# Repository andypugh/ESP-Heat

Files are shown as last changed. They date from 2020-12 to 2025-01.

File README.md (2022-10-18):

ESP32 Heating Controller
==============

A multi-zone central heating controller based on the ESP32.

It can be configured for an almost unlimited number of zones, pumps and separate boilers.
Boiler run-on is supported, and configurable. 
Temperature sensing assumes DS18B20 sensors. 
One zone per valve, and it is assumed that zone valves trip microswitches when open. 
 
Branches: 
no_master: Uses GPIO to read from the DS18B20 sensors

master: using a DS2482 1-wire master adaptor for longer cable runs. Using WebServer
to handle http requests. 

WiFiServer: Initial version using wiFi server and parsing incoming URLs byte-by-byte
 
The DS2482-100 is a I2C->1-Wire bridge (http://www.maximintegrated.com/datasheet/index.mvp/id/4382),
contains functionality that means it is better at driving long and complex networks. 

I used a DS2482-800 which additionally expands the bus to 8 separate channels, which allows
for longer single-ended networks.
For simplicity, using this break-out board. 
https://uk.rs-online.com/web/p/communication-wireless-development-tools/1360731/

Here is the main screen, showing a diagram of the house, with the temperature of each zone. 
The shape and position of each room is defined by an SVG path, for example:
"M250 350 v190 h140 v-190 z"
So that almost any house layout (or limited graphical elements for tanks etc) can be defined. 

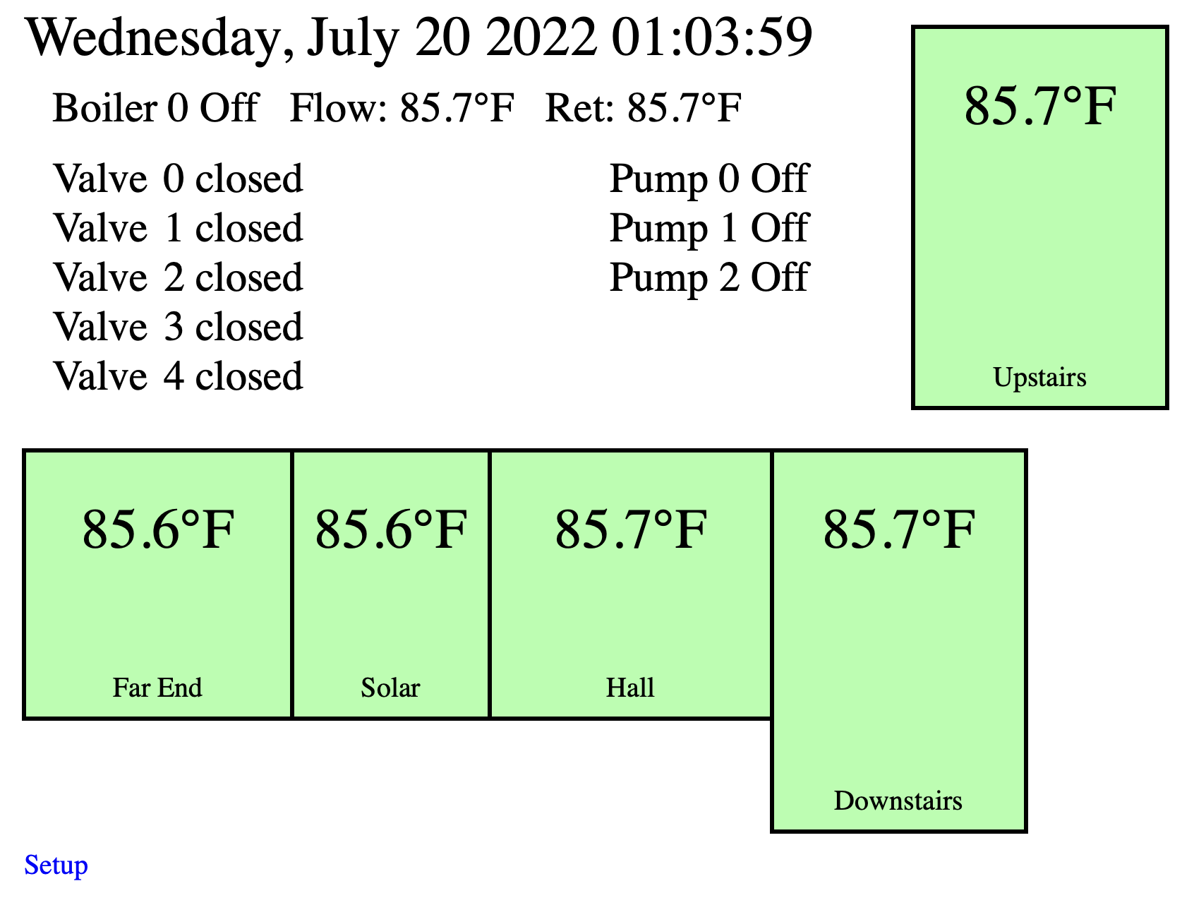
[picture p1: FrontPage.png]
Status screen
<kbd></kbd>

Here is one of the programming screens

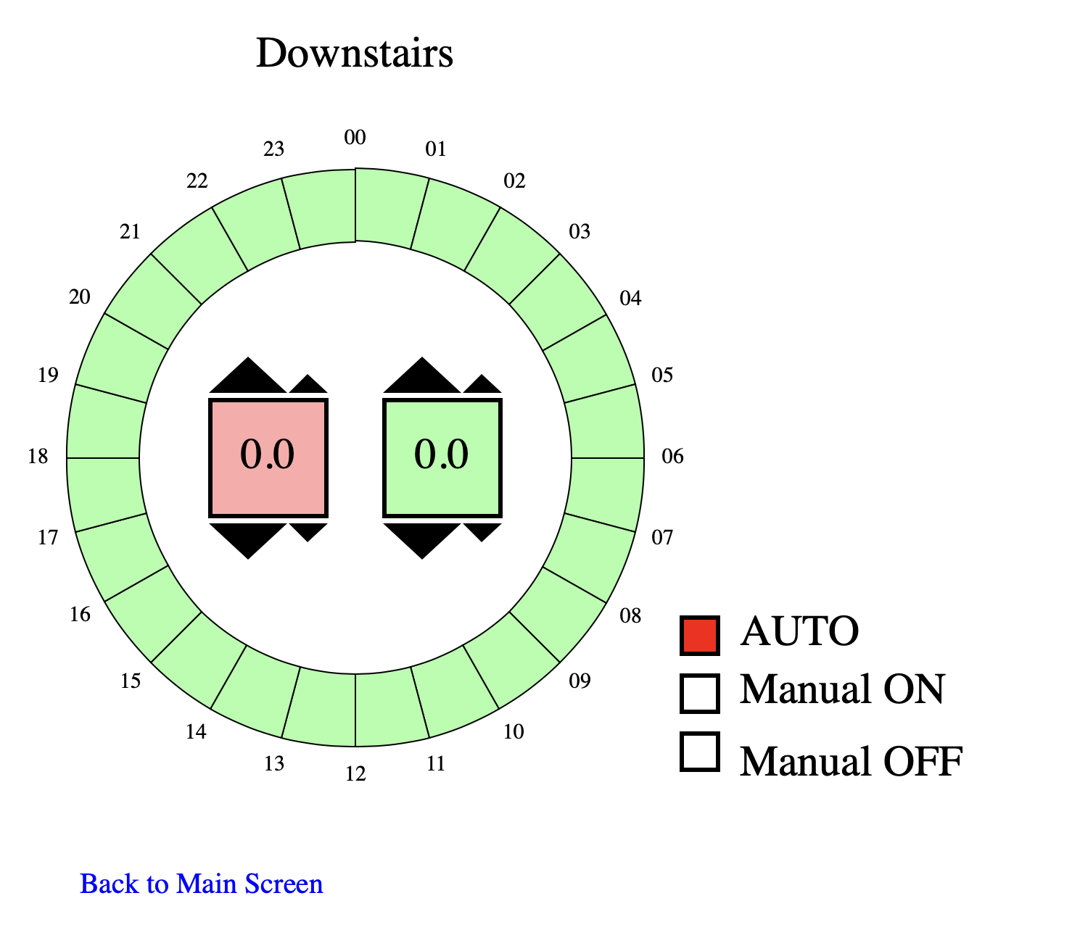
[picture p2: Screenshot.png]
Programming screen for one zone
<kbd></kbd>

And the setup screen where the pins for each valve and pump etc can be defined, as well
as the house layout and the temperature sensor allocation. 

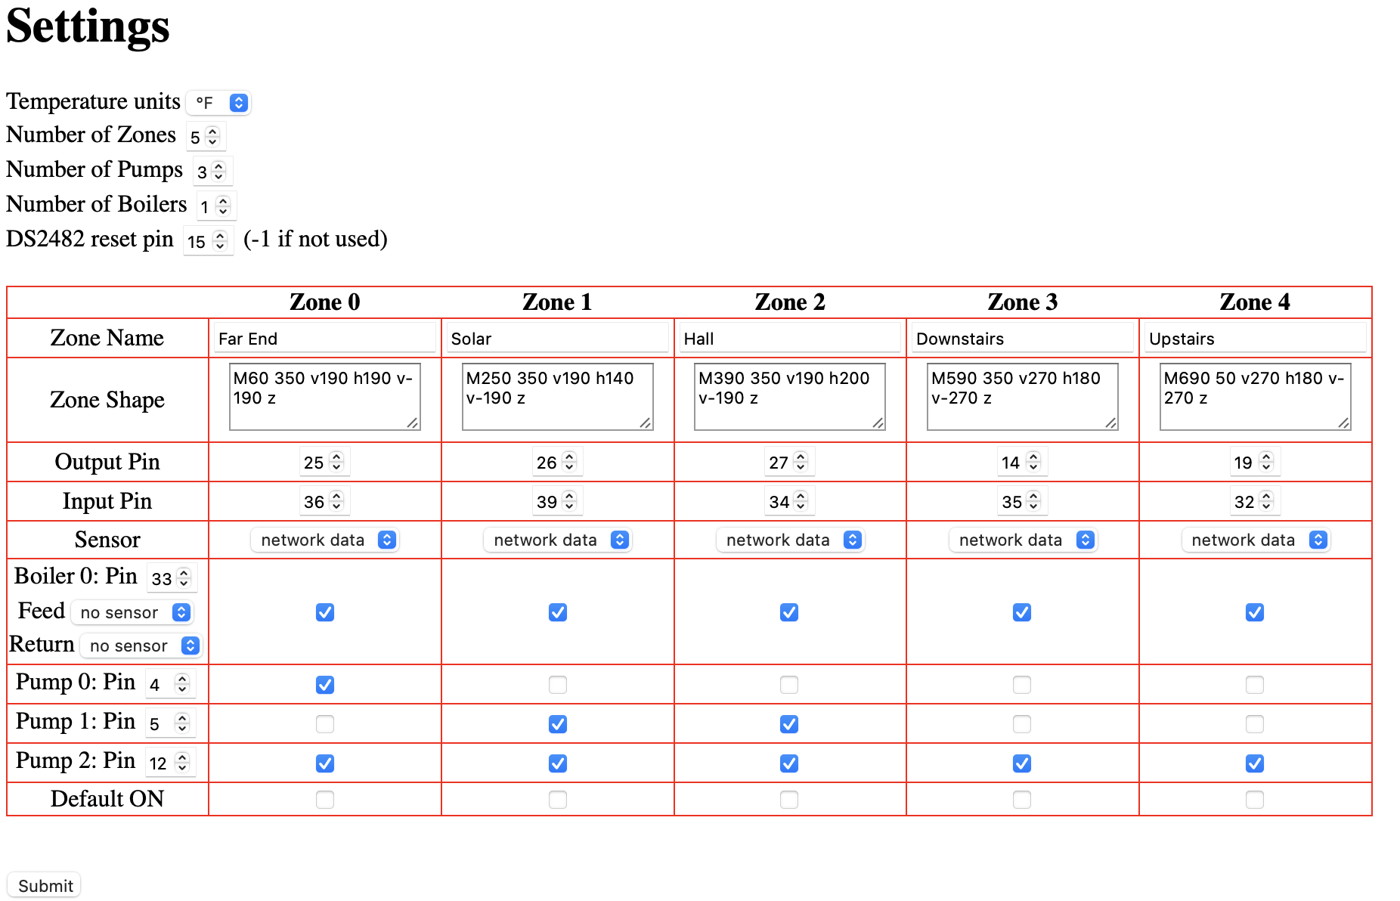
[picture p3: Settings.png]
Setup / Configuration Screen
<kbd></kbd>

And here is one iteration of the hardware installed in a consumer unit case with
Neutrik connectors for the pumps and valves and CB connectors for the temperature sensors:

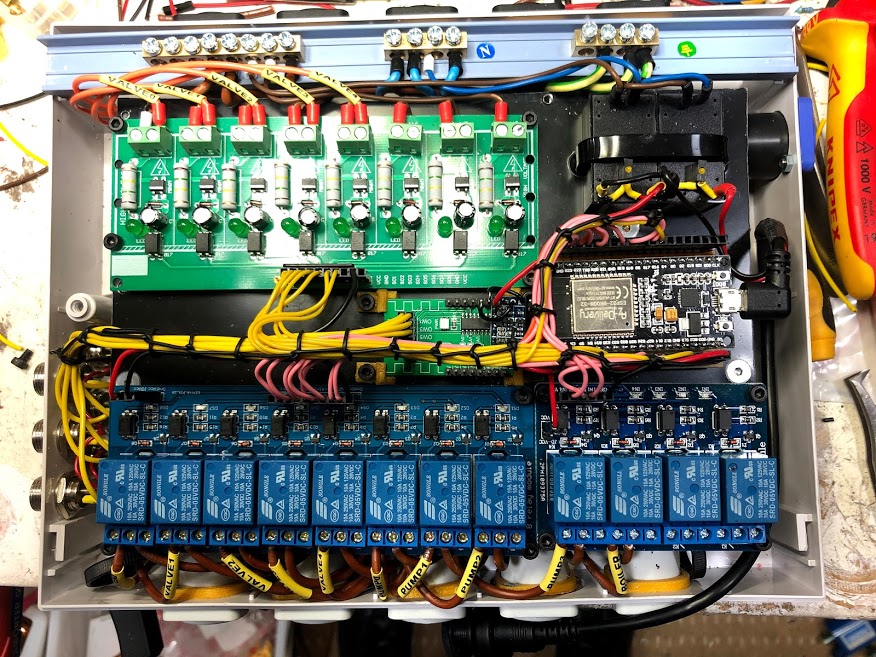
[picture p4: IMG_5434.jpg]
Hardware
<kbd></kbd>

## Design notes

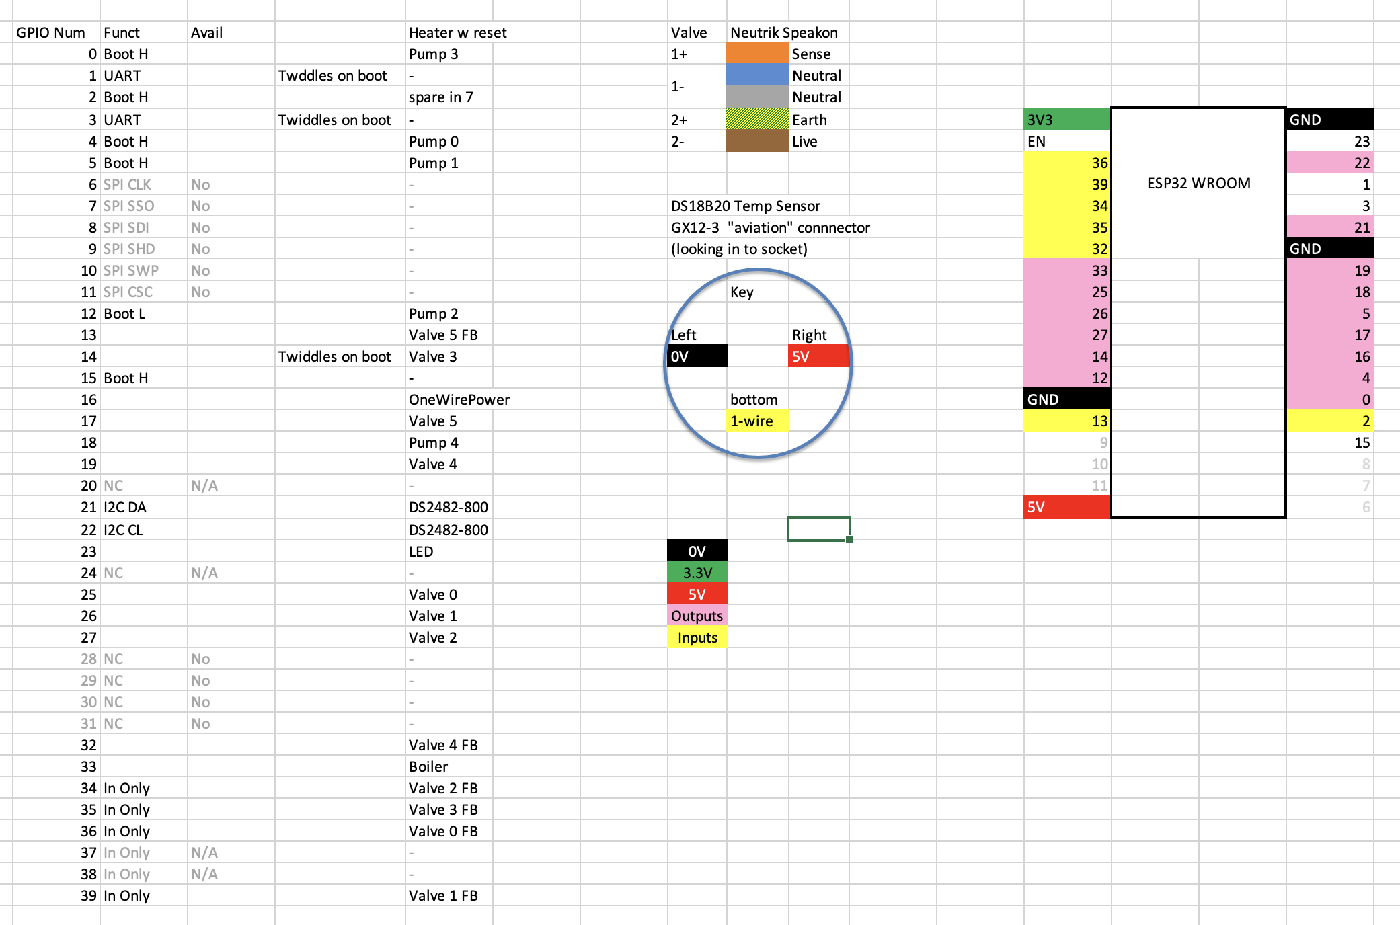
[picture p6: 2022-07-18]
Pinouts.png

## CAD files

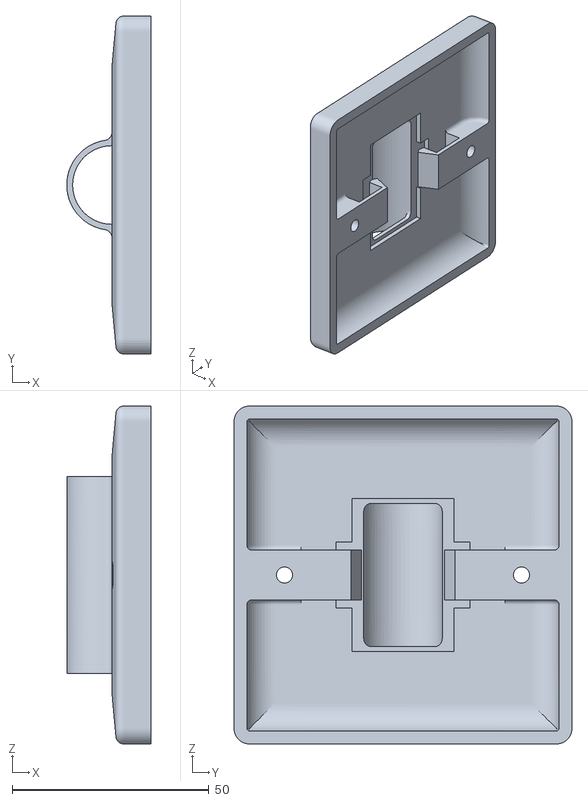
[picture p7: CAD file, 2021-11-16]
hardware/3D_Models/Temp Sensor v6.stl
21.5 x 86.0 x 86.0

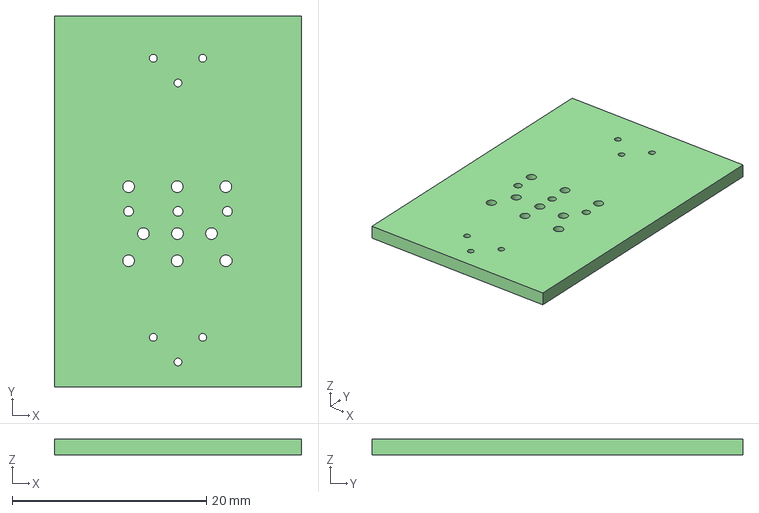
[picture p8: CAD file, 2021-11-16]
hardware/KiCad/Temp~Sensor.step
25.4 x 38.1 x 1.60 mm

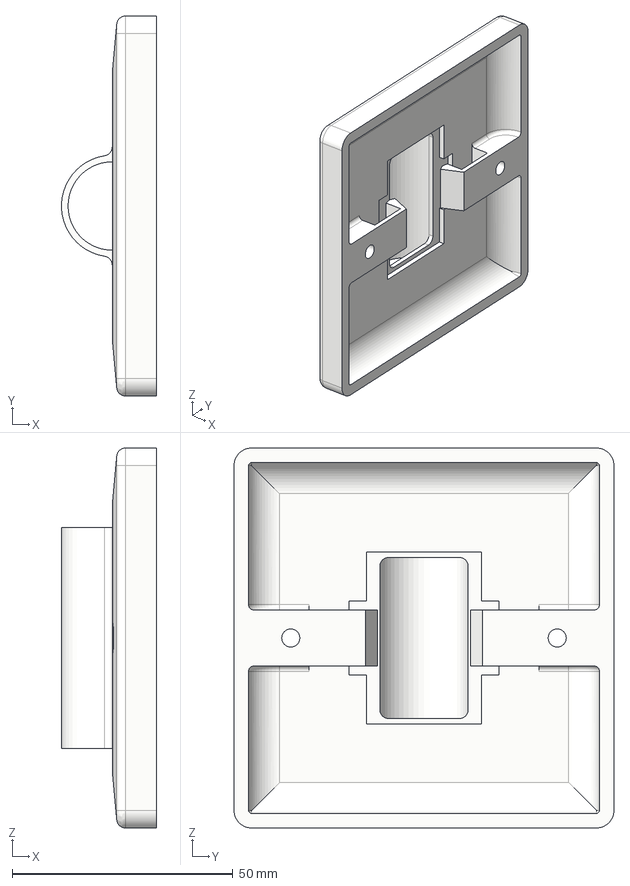
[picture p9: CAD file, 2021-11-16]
hardware/3D_Models/Temp Sensor v7.step
21.5 x 86.0 x 86.0 mm

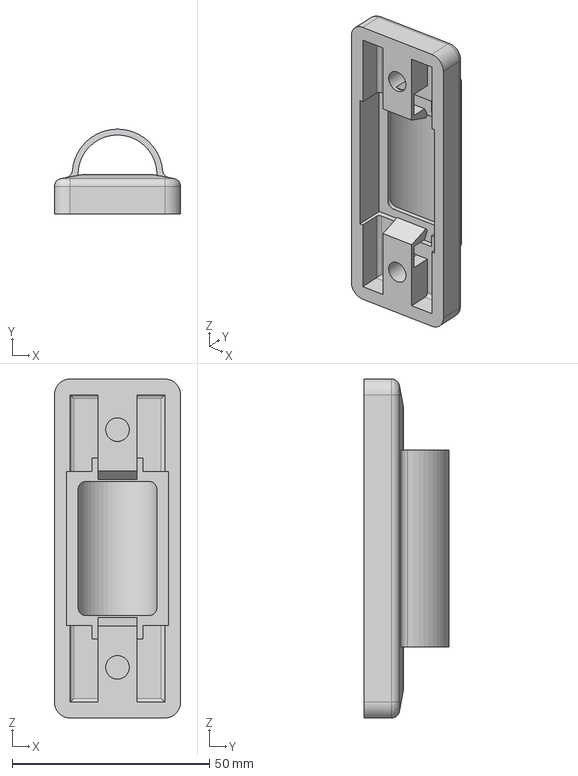
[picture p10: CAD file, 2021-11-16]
hardware/3D_Models/Temp Sensor - Architrave_Ds18B20 Holder - nut v2.step
32.0 x 21.5 x 86.0 mm

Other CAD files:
hardware/3D_Models/Temp Sensor - Architrave_Ds18B20 Holder - nut v2.f3d
hardware/3D_Models/Temp Sensor - Architrave_Ds18B20 Holder - nut v2.stl
hardware/3D_Models/Temp Sensor v6.f3z

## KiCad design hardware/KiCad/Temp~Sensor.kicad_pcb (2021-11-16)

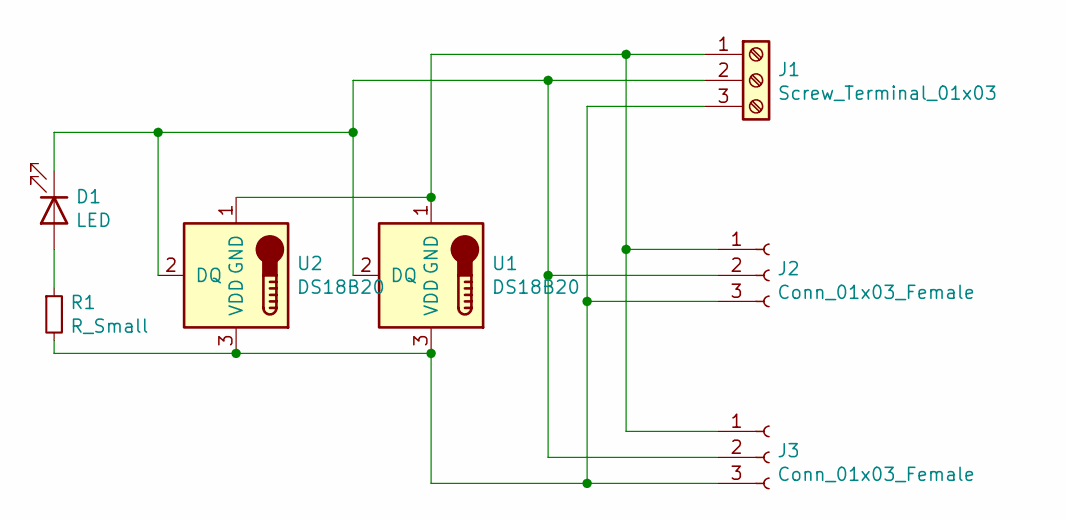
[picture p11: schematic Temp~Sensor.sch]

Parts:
D1: LED; LED_0603_HandSoldering
J1: Screw_Terminal_01x03; PhoenixContact_MCV-G_03x3.50mm_Vertical
J2: Conn_01x03_Female; Amphenol_FCI_3
J3: Conn_01x03_Female; RSProClamp
R1: R_Small; R_0603_HandSoldering
U1, U2: DS18B20; TO-92_Molded_Wide_Reverse

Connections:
unnamed: D1.1 (K), J1.2, J2.2, J3.2, U1.2 (DQ), U2.2 (DQ)
unnamed: D1.2 (A), R1.1
unnamed: J1.1, J2.1, J3.1, U1.1 (GND), U2.1 (GND)
unnamed: J1.3, J2.3, J3.3, R1.2, U1.3 (VDD), U2.3 (VDD)

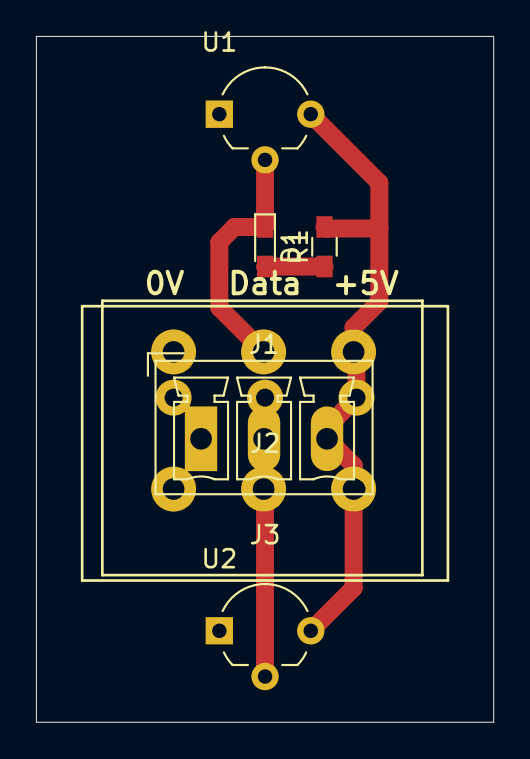
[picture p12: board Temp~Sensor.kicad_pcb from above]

Board: 2 copper layers, 25.4 x 38.1 mm, 7 parts (0 on the bottom side), 4 nets.

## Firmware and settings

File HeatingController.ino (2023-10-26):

 /*********
  Andy Pugh 2020

  Based on work by Rui Saontos: https://randomnerdtutorials.com
*********/

// Load Wi-Fi library

#include <WiFi.h>
#include <AsyncTCP.h>
#include <ESPAsyncWebServer.h>
#include <AsyncElegantOTA.h>
#include "ESP_Mail_Client.h"
#include "time.h"
#include "EEPROM.h"
// https://github.com/cybergibbons/DS2482_OneWire _NOT_ the standard library
// If using the DS2482. Otherwise use the standard OneWire lib
#include <OneWire.h>
#include <DallasTemperature.h>
#include "config.h"
#include "globals.h"

#define __P(f_, ...) snprintf (buffer, 200, (f_), ##__VA_ARGS__) ; content += buffer ;
//#define __P(f_, ...) snprintf (buffer, 200, (f_), ##__VA_ARGS__) ; Serial.println(buffer);

#ifdef USE_DS2482
OneWire oneWire(0); //I2C device address 0
#else
OneWire oneWire(23); //Bitbanged device, pin 23
#endif

DallasTemperature sensors(&oneWire);

// Set web server port number to 80
AsyncWebServer server(80);

int error_flag = 2; // 1 flash is just a heartbeat. use 2 to send reboot email

void setup() {
  int connection_count;

  Serial.begin(115200);
  
  EEPROM.begin(EEPROM_SIZE);

  pinMode(0, INPUT_PULLUP);

  // Get setup from eeprom
  read_EEPROM(EEPROM_BASE, true);
  read_EEPROM(CREDENTIALS_BASE, false);
  // Connect to Wi-Fi network with SSID and password
  Serial.print(" Connecting to ");
  Serial.println(ssid);
  WiFi.disconnect();
  WiFi.mode(WIFI_OFF);
  delay(1000);
  WiFi.config(INADDR_NONE, INADDR_NONE, INADDR_NONE, INADDR_NONE);
  WiFi.setHostname(hostname);
  WiFi.begin(ssid, password);
  WiFi.mode(WIFI_STA);
  pinMode(BLINK_LED, OUTPUT);
  pins[BLINK_LED] = 'x';
  do {
    if (! digitalRead(0)){ // boot button pressed
      Serial.println("boot button");
      AP_mode();
    }
    digitalWrite(BLINK_LED, HIGH);
    delay(250);
    WiFi.begin(ssid, password);
    Serial.print(WiFi.status());
    digitalWrite(BLINK_LED, LOW);
    delay(250);
    connection_count++;
  } while (WiFi.waitForConnectResult() != WL_CONNECTED && connection_count < 60);

  // Print local IP address
  Serial.println("");
  Serial.println("WiFi connected.");
  Serial.print("IP address: ");
  Serial.println(WiFi.localIP());
  Serial.print("MAC: ");
  Serial.println(WiFi.macAddress());
  Serial.printf("esp_idf_version %s\n", esp_get_idf_version());
 
  configTime(0, 3600, ntpServer);
  setenv ("TZ", TZstr, 1);
  tzset ();   // save the TZ variable

  // Get programming from eeprom)
  for (int i = 0; i < num_zones; i++) {
    zones[i].hours= EEPROM.read(i * 8 + 0) * 0x1000000L + EEPROM.read(i * 8 + 1) * 0x10000L + EEPROM.read(i * 8 + 2) * 0x100L + EEPROM.read(i * 8 + 3) * 0x1L;
    zones[i].on_temp =  EEPROM.read(i * 8 + 4); // 0 to 128 resolution 0.5 to allow for Farenheit
    if (zones[i].on_temp > 250) zones[i].on_temp = (units) ? 140 : 40; // in case if unintialised eeprom
    zones[i].off_temp = EEPROM.read(i * 8 + 5); // 0 to 128 resolution 0.5 to allow for Farenheit
    if (zones[i].off_temp > 250) zones[i].off_temp = (units) ? 80 : 10;
  }

  for (int i = 0; i < num_boilers; i++) {
    pinMode(boilers[i].out_pin, OUTPUT);
    pins[boilers[i].out_pin] = 'x';
    digitalWrite(boilers[i].out_pin, HIGH);
  }
  for (int i = 0; i < num_zones; i++) {
    pinMode(zones[i].out_pin, OUTPUT);
    pins[zones[i].out_pin] = 'x';
    digitalWrite(zones[i].out_pin, HIGH);
  }
  for (int i = 0; i < num_zones; i++) pinMode(zones[i].in_pin, INPUT_PULLUP);
  for (int i = 0; i < num_pumps; i++) {
    pinMode(pumps[i].out_pin, OUTPUT);
    pins[pumps[i].out_pin] = 'x';
    digitalWrite(pumps[i].out_pin, HIGH);
  }

  // Find which DS2482 channel each DS18B20 sensor can be found on

  num_sensors = 0;
  
#ifdef USE_DS2482

  if (ds2482_reset >= 0){
   // pinMode(ds2482_reset, OUTPUT);
   //digitalWrite(ds2482_reset, HIGH);
   // delay(1000);
   // oneWire.deviceReset();
   // delay(1000);
   // digitalWrite(ds2482_reset, LOW); // USE NC terminals, but sense is opposite for single relay
    pins[ds2482_reset] = 'x';
   // delay(2000);
  }
  sensors.begin();
  delay(1000);
  Serial.println("Searching for DS18B20 Sensors on DS2482");
  if (!oneWire.checkPresence()){
    Serial.println("DS2482 NOT found.");
  }else{
    Serial.println("DS2482 found.");
    for (byte c = 0; c < 8; c++) {
      oneWire.setChannel(c);
      if (oneWire.wireReset()){
        sensors.begin();
        Serial.printf("Checking channel %d\n", c);
        for (int j = sensors.getDS18Count() - 1; j >= 0; j--){
          sensors.getAddress(all_sensors[num_sensors].address, j);
          byte *a = all_sensors[num_sensors].address;
          sprintf(all_sensors[num_sensors].str_address,"%02X%02X%02X%02X%02X%02X%02X%02X", 
              a[0], a[1], a[2], a[3], a[4], a[5], a[6], a[7]);
          sprintf(all_sensors[num_sensors].dot_address,"%02x.%02x.%02x.%02x.%02x.%02x.%02x.%02x", 
              a[0], a[1], a[2], a[3], a[4], a[5], a[6], a[7]);
          Serial.printf("Found device addr %s\n", all_sensors[num_sensors].dot_address);
          all_sensors[num_sensors].channel = c;
          num_sensors = min(max_sensors, ++num_sensors);
        }
        for (int z = 0; z < num_zones; z++) {
          zones[z].temp=-127;
          if (sensors.isConnected(zones[z].sensor.address) && zones[z].sensor.channel >= 0) {
            Serial.printf("    Sensor for zone %i found\n", z);
            zones[z].sensor.channel = c;
          }
        }
        for (int z = 0; z < num_boilers; z++) {
          zones[z].temp=-127;
          if (sensors.isConnected(boilers[z].f_sensor.address) && boilers[z].f_sensor.channel >= 0) {
            Serial.printf("    Flow sensor for boiler %i found\n", z);
            boilers[z].f_sensor.channel = c;
          }
          if (sensors.isConnected(boilers[z].r_sensor.address) && boilers[z].r_sensor.channel >= 0) {
            Serial.printf("    Return sensor for boiler %i found\n", z);
            boilers[z].r_sensor.channel = c;
          }
        }
      }
    }
  }
  
#else
  sensors.begin;
  Serial.println("Searching for DS18B20 Sensors");
  DeviceAddress addr;
  while (! oneWire.search(addr)){
    oneWire.reset();
    delay(250);
  }
  oneWire.reset_search();
  while (oneWire.search(all_sensors[num_sensors].address)){
      byte *a = all_sensors[num_sensors].address;
      sprintf(all_sensors[num_sensors].str_address,"%02X%02X%02X%02X%02X%02X%02X%02X", 
          a[0], a[1], a[2], a[3], a[4], a[5], a[6], a[7]);
      sprintf(all_sensors[num_sensors].dot_address,"%02x.%02x.%02x.%02x.%02x.%02x.%02x.%02x", 
          a[0], a[1], a[2], a[3], a[4], a[5], a[6], a[7]);
      Serial.printf("Found device addr %s\n", all_sensors[num_sensors].dot_address);
      all_sensors[num_sensors].channel = 0;
      num_sensors = min(max_sensors, ++num_sensors);
  }
  for (int z = 0; z < num_zones; z++) {
    zones[z].temp=-127;
    if (sensors.isConnected(zones[z].sensor.address) && zones[z].sensor.channel >= 0) {
      Serial.printf("    Sensor for zone %i found\n", z);
    }
  }

#endif
  Serial.printf("Found a total of %i sensors\n", num_sensors);

// Set unused pins to their default state
  for(int i = 0; i < 39; i++){
      if (pins[i] == '0') {
          pinMode(i, OUTPUT);
          digitalWrite(i, LOW);
      } else if (pins[i] == '1') {
          pinMode(i, OUTPUT);
          digitalWrite(i, HIGH);
      } else if (pins[i] == 'i') {
          pinMode(i, INPUT);
      }   
      
  }
// Configure and start web server
// HTTP request pages are separate files
// And they seem to need to be .h as .cpp doesn't compile

#include "FrontPage.h"
#include "handleProgramming.h"
#include "handleSettings.h"
  AsyncElegantOTA.begin(&server);
  server.begin();
}

bool temp_valid(int z) {
  if (! units) {
    if (zones[z].temp > 80 || zones[z].temp < -100) return 0;
  } else {
    if (zones[z].temp > 180 || zones[z].temp < -100) return 0;
  }
  return 1;
}

void loop() {
  int t_fault = 0;
  int z = -1; // zone index
  int h = -1; // hour index
  char header[21] = {0}; int r = 0; // header buffer and index, ignore all but the first 20 chars
  AsyncElegantOTA.loop();
  do_status(); // blink-codes and connection housekeeping
  getLocalTime(&timeinfo);
  for (z = 0; z < num_zones; z++) {
    float demand_temp;
    bool off_flag = 0;

    zones[z].temp = get_temp(zones[z].sensor);

    if ((bitRead(zones[z].hours, timeinfo.tm_hour) || bitRead(zones[z].hours, 24)) && ! bitRead(zones[z].hours, 25)) {
      demand_temp = zones[z].on_temp / 2.0;
    } else {
      demand_temp = zones[z].off_temp / 2.0;
      off_flag = true; // Used to reset valve-stuck-closed
    }

    if ( ! temp_valid(z)) {
      t_fault++;
      // Handle default behaviour in faulted state
      if (zones[z].default_state) {
        if (off_flag) {
          demand_temp = -250;
        } else {
          demand_temp = +250;
        }
      } else {
        demand_temp = -250;
      }

      if (error_flag != 6){
        zones[z].timeout = time(NULL);
        error_flag = 6;
      } else {
        if (time(NULL) - zones[z].timeout > TIMEOUT){
#ifdef USE_DS2482
          if (ds2482_reset >= 0){
            Serial.printf("Resetting DS2482 HIGH on pin %i\n", ds2482_reset);
            oneWire.deviceReset();
            digitalWrite(ds2482_reset, HIGH);
            delay(10000);
            digitalWrite(ds2482_reset, LOW);
          }
#endif
          Serial.println("Resetting oneWire");
          oneWire.reset();
          zones[z].timeout = time(NULL);
        }
      }
    }
    /*************************************
          Valve control state machine
     *************************************/
    switch (zones[z].state) {
      case 0: // closed
        if (zones[z].temp < demand_temp - hyst) {
          digitalWrite(zones[z].out_pin, LOW);
          zones[z].state = 1;
          zones[z].timeout = time(NULL);
          Serial.printf("Turning On zone %d\n", z);
        }
        break;
      case 1: // valve opening
        if (! digitalRead(zones[z].in_pin)) { // valve has opened
          bitSet(zone_on, z);
          zones[z].state = 2;
          break;
        }
        if (time(NULL) - zones[z].timeout > timeoutTime) {
          error_flag = 5;
          zones[z].state = 5;
        }
        break;
      case 2: // Valve opened
        if (zones[z].temp > demand_temp + hyst) {
          digitalWrite(zones[z].out_pin, HIGH);
          zones[z].state = 3;
          zones[z].timeout = time(NULL);
          bitClear(zone_on, z);
          Serial.printf("Turning Off zone %d\n", z);
        }
        break;
      case 3: // valve closing
        if (digitalRead(zones[z].in_pin)) { // valve has closed
          zones[z].state = 0;
          break;
        }
        if (time(NULL) - zones[z].timeout > timeoutTime) { // timeout closing
          zones[z].state = 4;
          error_flag = 4;
        }
      case 4: // Stuck Open fault: We can still control temp, and it might close
        if (digitalRead(zones[z].in_pin)) { // valve has finally closed
          bitClear(zone_on, z);
          zones[z].state = 0;
          error_flag = 1;
          break;
        }
        if (zones[z].temp > demand_temp + hyst) {
          bitClear(zone_on, z);
        } else if (zones[z].temp < demand_temp - hyst) {
          bitSet(zone_on, z);
        }
        break;
      case 5: // stuck closed fault
        digitalWrite(zones[z].out_pin, HIGH); // avoid overheating motor
        bitClear(zone_on, z); // turn off the pump
        if (off_flag) {
          zones[z].state = 0;
          error_flag = 1;
        }
        break;
      default:
        error_flag = 10;
    }
  }

  if (t_fault == 0 && error_flag == 6) error_flag = 1;

  /*********************************
         Boiler State Machine
   *********************************/
  for (int i = 0; i < num_boilers; i++) {
 
    boilers[i].f_temp = get_temp(boilers[i].f_sensor);
    boilers[i].r_temp = get_temp(boilers[i].r_sensor);
 
    switch (boilers[i].state) {
      case 0: // boiler off
        if (zone_on && boilers[i].mask) {
          bitSet(boiler_on, i);
          digitalWrite(boilers[i].out_pin, LOW);
          boilers[i].state = 1;
        }
        break;
      case 1: // boiler on
        if (! zone_on && boilers[i].mask) {
          boilers[i].run_on_timer = time(NULL);
          bitClear(boiler_on, i);
          bitSet(run_on, i);
          boilers[i].state = 2;
          digitalWrite(boilers[i].out_pin, HIGH);
        }
        break;
      case 2: // run-on timer
        // check for timeout _or_ re-activation
        if (((time(NULL) - boilers[i].run_on_timer) > run_on_time) || (zone_on && boilers[i].mask)) {
          bitClear(run_on, i);
          boilers[i].state = 0;
          break;
        }
        break;
      default:
        error_flag = 10;
    }
  }
  /****************************
            Pump Control
   ****************************/
  for (int i = 0; i < num_pumps; i++) {
    if ((pumps[i].mask & zone_on) || (pumps[i].run_on_mask & run_on)) {
      digitalWrite(pumps[i].out_pin, LOW);
    } else {
      digitalWrite(pumps[i].out_pin, HIGH);
    }
  }
}

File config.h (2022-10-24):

// **************************CONFIGURATION************************************************

// maximum num_zones is EEPROM.BASE() / 8

#define max_zones 8
#define max_pumps 8
#define max_boilers 4
#define max_sensors 32
#define TIMEOUT 1800

#define USE_DS2482 

#define EEPROM_SIZE 1536
#define EEPROM_BASE 256
#define CREDENTIALS_BASE 1024

byte BLINK_LED = 23;
float hyst = 0.5; // temperature hysteresis

const char* boiler_states[3] = {"Off", "On", "Run-On"};
const char* valve_states[8] = {"closed", "opening", "open", "closing", "stuck open FAULT", "stuck closed FAULT", "sensor FAULT", ""};

unsigned long  run_on_time = 120; //seconds
const char* off_colour = "#aaffaa";
const char* on_colour = "#ffaaaa";

const unsigned long timeoutTime = 40;

// **************************/CONFIGURATION***********************************************

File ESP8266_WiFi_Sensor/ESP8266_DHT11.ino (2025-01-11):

#include <Adafruit_Sensor.h>
#include <DHT.h>
#include <ESP8266WiFi.h>
#include <ESP8266HTTPClient.h>
#include <EEPROM.h>

#define WIFI_SSID "slaithwaitehall"
#define WIFI_PASSWORD "harriet123456"
#define DHTPIN D4
#define DHTTYPE DHT11  // DHT 11
#define LED 2
#define DHTTYPE    DHT11     // DHT 11

DHT dht(DHTPIN, DHTTYPE);
char zone;
void setup() {
  EEPROM.begin(1);
  EEPROM.get(0, zone);
  pinMode(LED, OUTPUT);
  Serial.begin(115200);
  Serial.printf("Zone is set to %i\n", zone);
  WiFi.begin(WIFI_SSID, WIFI_PASSWORD);
  Serial.println("Connecting");
  while (WiFi.status() != WL_CONNECTED) {
    delay(200);
    digitalWrite(LED, LOW);  // turn the LED on.
    delay(100);
    digitalWrite(LED, HIGH);
  }
  Serial.println("");
  Serial.print("Connected to WiFi network with IP Address: ");
  Serial.println(WiFi.localIP());
}

void loop() {
  char serverPath[50];
  int ret;
  float temperature;

    
  if (Serial.available()){
    char buf[4];
    for(int i = 0; Serial.available() && i < 4; buf[i++] = Serial.read());
    zone = atoi(buf);
    Serial.printf("Setting the zone for this device to %i\n", zone);
    EEPROM.write(0, zone);
    EEPROM.commit();
  }

  delay(100);             // wait for 1 second.
  digitalWrite(LED, HIGH);  // turn the LED on.
  delay(10000);
  digitalWrite(LED, LOW);

  temperature = dht.readTemperature();

  if(WiFi.status()== WL_CONNECTED && ! isnan(temperature)){
      WiFiClient client;
      HTTPClient http;

      int ret = sprintf(serverPath, "http://heating.local/update_temp?zone=%i&temp=%02.2f", zone, temperature);
      Serial.println(serverPath);
      http.begin(client, serverPath);
  
      // Send HTTP GET request
      int httpResponseCode = http.GET();
      
      if (httpResponseCode>0) {
        Serial.print("HTTP Response code: ");
        Serial.println(httpResponseCode);
      }
      else {
        Serial.print("Error code: ");
        Serial.println(httpResponseCode);
      }
      // Free resources
      http.end();
    }
    else {
      Serial.println("WiFi Disconnected");
    }

}

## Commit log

2020-11-07 prepare to use DS2842 one-wire master
2020-11-08 Switch to using DS2482-800 1-wire hub
2020-11-14 Wired up, nearly working
2020-11-15 Add led blnk error codes
    [HeatingController.ino]
2020-11-15 switch back to WiFiServer for this branch
2020-11-24 Create sample credentials.h file
    This will need to be configured to suit your setup.
    If the error_email is a null string ("\0") then error email sending will be disabled
2020-12-17 Allow zone temperature to be set by a URL request for example by a remote ESP32. Also allow error modes to heal
    [HeatingController.ino]
2020-12-17 Send emails on error conditions
    [HeatingController.ino]
2020-12-17 Move GetTemperatures() so that all channels are updated. Also list addresses of found sensors
2021-10-18 Add external IP to notifications. Add reset magig-URL
    [HeatingController.ino]
2021-10-28 Major refactor. Zones, pumps, boilers as structs. Broken into many files
    [HeatingController.ino, config.h]
2021-10-30 Zone names fixed. Floorplan still needs doing
    [Status.ino, globals.h]
2021-10-30 Fix typos in DS2482 mode
    [HeatingController.ino, config.h]
2021-10-31 Add boiler feed and return sensor handling
2021-11-16 Attempt to improve sensor error handling Also switch to using clock time for timeouts.
    [HeatingController.ino, config.h, globals.h]
2021-11-16 Add PCB and 3D model files
    [Temp Sensor - Architrave_Ds18B20 Holder - nut v2.f3d, Temp Sensor - Architrave_Ds18B20 Holder - nut v2.step, Temp Sensor - Architrave_Ds18B20 Holder - nut v2.s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]
2021-12-26 Zone active bit was set wrongly
    [HeatingController.ino]
2022-07-15 Add relay control to power-off reset the temperature sensors
    [HeatingController.ino, config.h, globals.h]
2022-07-17 Add a pin to power-of reset the OneWire hub
    [HeatingController.ino, globals.h]
2022-07-18 Fix default pin init bug
    [globals.h]
2022-07-18 Pinouts of controller and ESP32
2022-07-18 Rework DS2482 reset. Add timeout info. Deboince programmingn URLS
    [HeatingController.ino, config.h]
2022-10-23 Fix resetting of bitmasks, make network settings available outside AP mode
    [HeatingController.ino, Status.ino, config.h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]
2022-10-24 revert something odd in a merge
    [HeatingController.ino]
2023-10-26 Attempt to improve default-on behaviour with faulted sensors
2023-10-26 Fix default behaviour some more
    [HeatingController.ino]
2025-01-11 Add ESP8266/DHT11 sensor
